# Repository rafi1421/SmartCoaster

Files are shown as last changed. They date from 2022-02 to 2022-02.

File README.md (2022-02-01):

# SmartCoaster
When I'm working, I get so focused that I forget to drink water. It's not that I'm not thirsty—oh, I am—but I'll get a glass of water, put it down on my desk, and forget all about it for hours.

The Smart Coaster is meant to help with that bad habit by giving me an easy visualization of how long it's been since I last took a drink. It does this simply by running through a program that changes the color and brightness of LEDs over time, with a momentary switch that is pressed down by the weight of a glass on top of it. When I pick up a glass and put it back down, it resets the timer. If it's been way too long since I last took a sip, the lights will blink until I do something about it.

This device isn't meant to track consumption, log data, or help achieve any quantity goals. It's just here to remind me, once in a while, to reach over and take a sip.

**V3 Forked by Rafi**
This project is a fork of V2 because I wanted the microcontroller and LEDs to react differently than the original designer.

The V2 code seems to always have the leds on and pulsing whether or not the button was pressed. I changed this so when the button is not pressed, ie. no cup placed on the coaster, the leds are off. Only when the button has been depressed for 30 minutes, the blue led will slowly fade on as time progresses. From there the red led fades in while blue fades out to create a purple and continues to glow only red as the time approaches 60 minutes, indicating "hey its been an hour and you haven't lifted up the cup, you should really drink some water now." It will then remain lit red for about an hour and then turn off assuming that you simply left the area and wont return anytime soon.

Another feature of this update is an attempt to reduce power consumption. While yes, leds being fully lit use way more energy than the little mA reductions by using and idle_power mode vs normal mode, its still something and would rather include it, especially since the project isn't doing much besides turn on lets and keep time. ADC is turned off, as well as timer1, since only timer0 is needed for PWM. While the button is not pressed, it goes into a full power down sleep mode, saving the most energy, where only the button being pressed will act as an interrupt to wake up the cpu. The following links are blogs I've used in the past to achieve low power and simply reused the code here and adjusted some registers to conform to the digispark board.

https://www.electro-tech-online.com/articles/achieving-low-power-on-adafruit-trinket.830/

http://www.gammon.com.au/forum/?id=11497

## Board Design
The lights are driven by a small Arduino board, like the Micro or Adafruit ItsyBitsy—it's developed on and tested with Atmel 32U4-based boards, but just about any controller should work.

**V1**
The first prototype coaster uses four WS2812B RGB LED chips and the Adafruit NeoPixel Arduino library. They're tied into pin 6 of the microcontroller and fed instructions to change color based on the counter value.

**V2**
The second prototype uses four-pin common cathode RGB LEDs connected to three PWM pins on the microcontroller. Color values are set by directly analogWriting to the R, G and B pins. Since all the lights are showing the same color value, this seems like a simpler solution.

V2 also introduced a potentiometer control for setting the alert time.

**V3**
Circuit remained relatively the same except i'm using a DigiSpark board and am not using a potentiometer since I dont want to play with setting an alert time. Rather play around with the desired alert time in code and then leave it alone.

Attaching my STL files I modeled and 3D printed.

Demo Gif

https://imgur.com/so1dpxB.gif

A future idea if I were to do it again, would be to use a magnetic switch(Hall Effect Sensor), that way I dont need to precisely measure the height of the button/cap/holder & its switch distance and create the top cover to account for all of those while keeping the differ wall hidden, while also trying to maintain a low profile. Another reason is because the switch and the top cover without any filler/foam will introduce an uneven balance point because of the switch being in contact with both the base and top cover, so I had to use some foam to make it balanced. A magnetic sensor will allow the two pieces slide past each other without being in physical contact.

V2 board wiring diagram

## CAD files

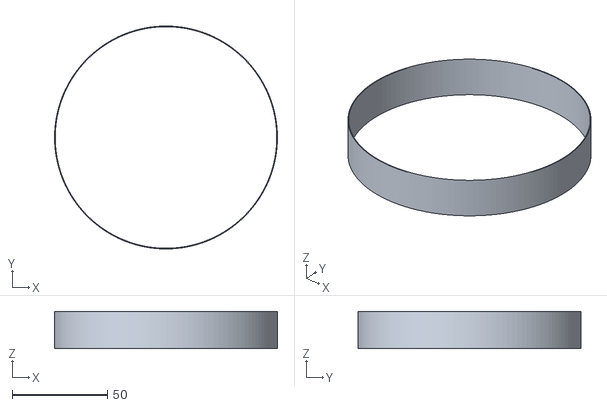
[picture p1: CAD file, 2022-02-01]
SmartCoaster_STLs/coaster v59 - diffuser wall.stl
116.8 x 116.8 x 19.5

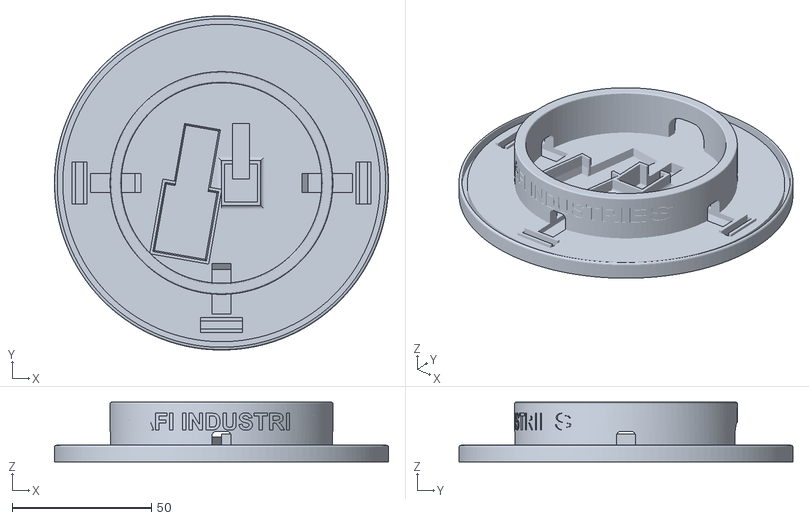
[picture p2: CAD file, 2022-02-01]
SmartCoaster_STLs/coaster v59 - base.stl
120.0 x 120.0 x 21.5

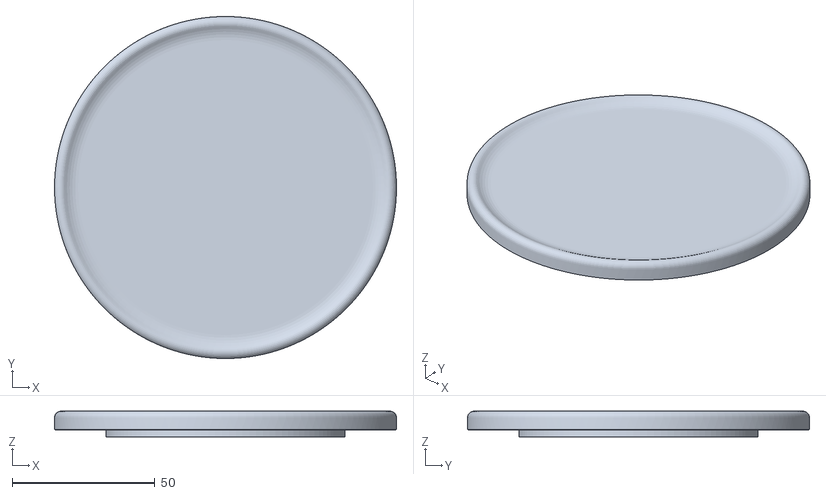
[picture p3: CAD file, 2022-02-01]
SmartCoaster_STLs/coaster v59 - top lid.stl
120.0 x 120.0 x 8.96

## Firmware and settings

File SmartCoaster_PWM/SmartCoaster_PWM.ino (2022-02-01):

#include <avr/power.h> // Needed to enable/disable power modes

#define Board_DigiSpark true

#if Board_DigiSpark
  //DigiSpark Pins
  #define RPIN 0
  #define GPIN 4
  #define BPIN 1
  #define BUTTON_PIN 2
  byte BUTTON_INT = 2;  // however arduino reference says now to use -> digitalPinToInterrupt(BUTTON_PIN). However this function doesnt exist on digispark?
  #define DEBUG_serial false    // serial print messages
#else
  //Arduino Mega Pins
  #define RPIN 5
  #define GPIN 6
  #define BPIN 7
  #define BUTTON_PIN 21
  byte BUTTON_INT = 2; // however arduino reference says now to use -> digitalPinToInterrupt(BUTTON_PIN).
  #define DEBUG_serial true    // serial print messages
#endif 


int counter = 0;

int red = 255;
int green = 255;
int blue = 255;
int blue_old = 0;
int red_old = 0;

int adjustmentValue = 0;
int buttonValue = 0;
bool buttonDown = false;
bool skipNap = false;

#define thresh_min 25
#define thresh_mid 40
#define thresh_max 60
#define thresh_max_hold 50
#define LEDMAXBRIGHT 200


//// Watchdog intervals
//// sleep bit patterns for WDTCSR/
enum {
  WDT_16_MS  = 0b000000,
  WDT_32_MS  = 0b000001,
  WDT_64_MS  = 0b000010,
  WDT_128_MS = 0b000011,
  WDT_256_MS = 0b000100,
  WDT_512_MS = 0b000101,
  WDT_1_SEC  = 0b000110,
  WDT_2_SEC  = 0b000111,
  WDT_4_SEC  = 0b100000,
  WDT_8_SEC  = 0b100001,
};  // end of WDT intervals enum



void setup() {

  #if DEBUG_serial
	Serial.begin(115200);
  //Serial.print(" BUTTON_PIN to Intterupt: ");
  //Serial.println(digitalPinToInterrupt(BUTTON_PIN));
  #endif // DEBUG

  
  pinMode(RPIN, OUTPUT);
  pinMode(GPIN, OUTPUT);
  pinMode(BPIN, OUTPUT);

  pinMode(BUTTON_PIN, INPUT_PULLUP);

  // PowerOn glow for fun
  fadeOn(BPIN,50);
  fadeOn(GPIN,50);
  fadeOut(BPIN,50);
  fadeOut(GPIN,50);
  power_adc_disable(); // wont need adc in a normal operation #include power.h
}

void loop() {

  buttonValue = digitalRead(BUTTON_PIN);

#if DEBUG_serial
  Serial.print(" ButtonValue: ");
  Serial.print(buttonValue);
  Serial.print(", ButtonDown: ");
  Serial.print(buttonDown);  
  Serial.print(", Counter: ");
  Serial.print(counter);
  Serial.print(", red: ");
  Serial.print(red);
  Serial.print(", green: ");
  Serial.print(green);
  Serial.print(", blue: ");
  Serial.println(blue);
#endif
  
  if (buttonValue == LOW && buttonDown == false) {
    counter = 0;
    buttonDown = true;
    //counter++;
    #if DEBUG_serial
      Serial.println("+++ Button Pressed. Starting Watchdog +++ ");
      delay(10);
    #endif
  } 
  else if (buttonValue == LOW && buttonDown == true) {
    counter ++;
    #if DEBUG_serial
      Serial.println("--- Button Still Pressed. Watchdog keeping guard --- ");
      delay(10);
    #endif
    
    //Enable ISR to allow wake up during watchdog and skip the reset of the sleep cycles in the routine with skipNap.
    #if Board_DigiSpark
      EnablePinChangeInt(BUTTON_INT);
    #else
      attachInterrupt(BUTTON_INT, WakeUp, CHANGE); //digispark doesnt support this method
    #endif
    // Repeat 8 second watchdog to elapse a minute's length. 
    // Should be 7.5 times for a minute, but i think because of the reduced 1KHz clock, it runs a bit slower? So eight 8 second sleep cycles covers close to 58 seconds on my board.
    for (int x = 0; x < 7; x++) {
      if (!skipNap) {
        EnableWatchdog(WDT_8_SEC);
        GoToSleep(SLEEP_MODE_IDLE);
      } else {
          #if DEBUG_serial
            Serial.println(" *.* Skipping Nap .*. ");
            delay(10);
          #endif
      }
    }
//    if (!skipNap) {
//      EnableWatchdog(WDT_4_SEC);
//      GoToSleep(SLEEP_MODE_IDLE);
//      #if DEBUG_serial
//        Serial.print(" // ");
//        Serial.print(counter);
//        Serial.println(" minutes elapsed // ");
//        delay(10);
//      #endif
//    }
    #if Board_DigiSpark
      DisablePinChangeInt();
    #else
      detachInterrupt(BUTTON_INT);  //digispark doesnt support this method
    #endif
    
  }
  else if (buttonValue == HIGH && buttonDown == true) {
    counter = 0;
    buttonDown = false;
    #if DEBUG_serial
      Serial.println("+++ Button Raised. Clearing counter +++ ");
      delay(10);
    #endif
  }
  else if (buttonValue == HIGH && buttonDown == false) {
    counter++;
    #if DEBUG_serial
      Serial.println("--- Button Not Pressed. Going into pwd_down --- ");
      delay(10);
    #endif
    
    // Enable ISR and Sleep
    #if Board_DigiSpark
      EnablePinChangeInt(BUTTON_INT);
    #else
      attachInterrupt(BUTTON_INT, WakeUp, CHANGE); //digispark doesnt support this method
    #endif    
    GoToSleep(SLEEP_MODE_PWR_DOWN);
    #if Board_DigiSpark
      DisablePinChangeInt();
    #else
      detachInterrupt(BUTTON_INT);  //digispark doesnt support this method
    #endif
    
    #if DEBUG_serial
      Serial.println("--- Button Pressed Down -> Woke up from pwd_down --- ");
      delay(10);
    #endif
  }
  
  skipNap = false;
  evaluateColors();
  updateLights();
}


void evaluateColors() {
  if (buttonDown == true && counter > thresh_min && counter <= thresh_mid) { //blue
    int adjustmentRange = map(counter, thresh_min, thresh_mid, 0, LEDMAXBRIGHT);
    fader(BPIN, blue_old, adjustmentRange, 700);
    red = 0;
    green = 0;
    blue = adjustmentRange;
  } else if (buttonDown == true && counter > thresh_mid && counter <= thresh_max) { //blue to purple to red
    int adjustmentRange_r = map(counter, thresh_mid, thresh_max, 1, LEDMAXBRIGHT);
    int adjustmentRange_b = map(counter, thresh_mid, thresh_max, LEDMAXBRIGHT, 0);
    fader(RPIN, red_old, adjustmentRange_r, 200);
    red = adjustmentRange_r;
    green = 0;
    blue = adjustmentRange_b;
  } else if (buttonDown == true && counter > thresh_max && counter <= thresh_max+thresh_max_hold) { //hold red for a bit
  } else if (buttonDown == true && counter > thresh_max+thresh_max_hold) { //turn off leds
    red = 0;
    green = 0;
    blue = 0;
  }

  if (buttonDown == false) {
    red = 0;
    green = 0;
    blue = 0;
  }

}

void updateLights() {
    analogWrite(RPIN, red);
    analogWrite(GPIN, green);
    analogWrite(BPIN, blue);
    blue_old = blue;
    red_old = red;
}

void fadeOn(int LEDPIN, int LedBrightness) {
    int fadeLed;
    for (int x = 0; x < LedBrightness; x++) {
      fadeLed = .015*x*x;
      analogWrite(LEDPIN, fadeLed);
      delay(30);
    }
}
void fadeOut(int LEDPIN, int LedBrightness) {
    int fadeLed;
    for (int x = LedBrightness; x > 0; x--) {
      fadeLed = .015*x*x; 
      analogWrite(LEDPIN, fadeLed);
      delay(10);
    }
    digitalWrite(LEDPIN, LOW); //turn off pwm bits
}
void fader(int LEDPIN, int LedLast, int LedTo, int incDelay) {
    for (int x = LedLast; x < LedTo; x++) {
      analogWrite(LEDPIN, x);
      delay(incDelay);
  }
}

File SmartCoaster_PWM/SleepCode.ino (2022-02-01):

// Trinket Sleep code

#include <avr/sleep.h> // Needed for sleep_mode
#include <avr/wdt.h> // Needed to enable/disable watchdog timer
#include <avr/power.h> // Needed to enable/disable power modes
#include <avr/interrupt.h>




void EnableWatchdog() {
  EnableWatchdog(WDT_1_SEC);
}
void EnableWatchdog(const byte interval) {
  MCUSR = 0;
  // allow changes, disable reset
  #if Board_DigiSpark
    WDTCR = _BV(WDCE) | _BV(WDE);
  #else
    WDTCSR = _BV(WDCE) | _BV(WDE);
  #endif
  // set interrupt mode and an interval
  #if Board_DigiSpark
    WDTCR = _BV(WDIE) | interval;    // set WDIE, and requested delay
  #else
    WDTCSR = _BV(WDIE) | interval;    // set WDIE, and requested delay
  #endif
  wdt_reset();  // pat the dog
}
ISR(WDT_vect)
{
  wdt_disable();  // disable watchdog
}

#if Board_DigiSpark
void EnablePinChangeInt(byte const ShiftBy) {
//  sensorActive = false; 
  // Pin Change Interrupt setup
  GIMSK = 0b00100000;               // turns on pin change interrupts
  PCMSK = 0b00000001 << ShiftBy;    // turn on interrupts on pins PB#
}
void DisablePinChangeInt() {
  // Pin Change Interrupt setup
  GIMSK = 0b00000000;    // turns off pin change interrupts
  PCMSK = 0b00000000;    // turn off interrupts on pins PB#
}
#endif

ISR(PCINT0_vect)
{
    skipNap = true;             // Increment volatile variable
}


//
// Well apparently attchInterrupt() & detachInterrupt() work for arduino & trinket, but not the digispark. So need to use PCINT, which is fine for my use.
// Maybe those functions can be replaced with more hardware specific code.
//
// Use:   attachInterrupt(LightSensorInt, WakeUp, LOW); // HW INT0
void WakeUp() {
  skipNap = true;
  //maybe leave this empty here so i dont need to change the pin variable in future projects, and just use this line directly in the code where is resumed.
  //detachInterrupt(digitalPinToInterrupt(BUTTON_PIN));
}

//void GoToSleep() {
//  GoToSleep(SLEEP_MODE_PWR_DOWN);
//}
void GoToSleep(const byte mode) {
  // disable ADC
  byte old_ADCSRA = ADCSRA;
  ADCSRA = 0;

  // turn off various modules
  if (mode == SLEEP_MODE_PWR_DOWN) {
    power_all_disable();
  }
  else {
    power_adc_disable();
    // These keep PWM while IDLE sleeping
    #if Board_DigiSpark
       // DigiSpark/Digistump appears to set or use this register(bit 2) for timer overflow ISR which was causing the CPU to immediately wake up from sleep while using PMW.
      //  This turns off that bit and allows PWM to work while in SLEEP_MODE_IDLE
      int v_TIMSK = TIMSK;
      bitClear(v_TIMSK,2);
      TIMSK =v_TIMSK;
      
      power_timer1_disable();
      //power_timer0_disable(); // WELL APARENTLY this is what was screwing up causing the led's to flicker on the digispark! but it wouldnt flicker on the arduino! Strange! Probably uses different timers or modes or something like that.
      //// im guessing pin 4 runs on timer 1 while pins 0 & 1 run on timer 0. in that case since im only using blue and red, i can swap the green pin with blue so i can disable clock 1 and keep clock 0 only without problem so i can at least save some power.
      //// side note, that power draw warning on windows only happens when a timer is disabled? could it being off while trying to toggle the pin cause an internal short somewhere? interesting.
      //// back to that flicker issue, ran a test only disabling timer 1 while keeping timer 0 alive, so R&B pwm can work but G wont, then after 30 seconds, i got the windows error, and now its flickering white, because in the code i have all 3 going. so its definetly got to do with the internals & registers that is different in the digispark compiler compared to trinket/arduino. Well at least in a plain pwm/sleep sketch, stillshows that windows error in this project.
      #endif
  }
  
  // --- start timed sleep sequence (order of events matter) --- //
  noInterrupts();
  sleep_enable();
  set_sleep_mode (mode);
  #ifndef Board_DigiSpark 
  sleep_bod_disable();
  #endif
  interrupts();
  sleep_mode();
  // --- end timed sleep sequence (order of events matter) --- //
  // - WAKEUP FROM SLEEP - //
  sleep_disable();
  //noInterrupts(); //Whoa, so actually having this here is what was causing the problem "reseting" during/after sleep!
  power_all_enable();
  ADCSRA = old_ADCSRA;  //return ACD enabled
}

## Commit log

2022-02-01 Adjust Pinout for Arduino Mega
    and demo source program
    Will convert to use ATtiny85 pins later. Using mega I can debug easier with serial print
    Move V1 code that uses a w2812B LED strip into its own folder rather than being in root.
2022-02-01 Create my button down glow pattern
    add some serial print
    change led glow to pattern i like:
    blue->add red glow -> remove blue until completely red at max time -> blank after too long
    [SmartCoaster_PWM.ino]
2022-02-01 Digispark Demo
    Glow the leds after a few seconds of button press.
    Add pinouts for digispark vs arduino mega
2022-02-01 Iron out Led color fades
2022-02-01 Power on glow sequence for fun
2022-02-01 Incorporate watchdog & sleep functions to replace delay()
    When button isnt pressed: powerdownsleep
    When button pressed: idle sleep to allow pwm to function during watchdog
    Compiled and tested operation of sleep first on arduino mega with debug print statements then on digispark.
    Added #if directives to help compile arduino&digispark since there seems to be a unsupported variables/functions in sleep.h/wdt.h
    Added "ShiftBy" parameter to EnablePinChangeInt and comment to WakeUp() when used on arduino projects to make it more reuseable if used again in next project
    [SleepCode.ino, SmartCoaster_PWM.ino]
2022-02-01 Resolve Sleep_Mode_Idle bugs specific to the digispark board
    Needed to research/debug which timers belongs to which pwm pins while also finding out that the digispark incorporates a timer overflow Interrupt Serive Routine (ISR) when using PWM which would wake up the cpu frontrunning the sleep/watchdog session. The Trinket & Arduino boards do not exibit this issue when tested with the same code.
    Some notes also in code speaking about this:
    power_timer1_disable();
    //power_timer0_disable(); // WELL APARENTLY this is what was screwing up causing the led's to flicker on the digispark! but it wouldnt flicker on the arduino! Strange! Probably uses different timers or modes or somethin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
    [SleepCode.ino, SmartCoaster_PWM.ino]
2022-02-01 Include a fader inbetween brightness increments
    Now since the brightness increment calculation occurs every minute, the gap between the two values when updated is a somewhat noticable but not too bad. Decided to throw in a fader() to blend the bri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
    Adjust Minute Sleep timer. Should be 7.5 times for a minute, but I think because of the reduced 1KHz clock, it runs a bit slower? So eight 8 second sleep cycles covers close to 58 seconds on my board.
2022-02-01 Upload STLs
    A future idea if I were to do it again, would be to use a magnetic switch(Hall Effect Sensor), that way I dont need to precisely measure the height of the button/cap/holder & its switch distance and 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
    [coaster v59 - base.stl, coaster v59 - diffuser wall.stl, coaster v59 - top lid.stl]
